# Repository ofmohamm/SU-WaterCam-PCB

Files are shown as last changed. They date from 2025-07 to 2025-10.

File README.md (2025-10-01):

# SU WaterCam PCB

This repository contains the KiCad design files for a custom PCB for **SU-WaterCam**, integrating the FLIR Lepton thermal camera, Bosch BNO055 IMU, Multitech mDot LoRa module, and Witty Pi 4 RTC board. 

---

## 🔧 Design Overview

- **Layers**: 2-layer PCB (F.Cu, B.Cu)
- **Components**:
  - FLIR Lepton thermal imaging module
  - Bosch BNO055 9-DOF absolute orientation sensor
  - Multitech mDot LoRa module
  - Witty Pi 4 RTC and power manager
- **Power Domains**:
  - 3.3V and 5V rails with copper fill zones
  - Mounting via Witty Pi 4-compatible headers
- **Interfaces**:
  - FFC cutout for FLIR Lepton
  - I²C / UART routing for sensors
  - LoRa antenna trace or u.FL footprint

---

## Electrical & Layout Highlights

- **Trace widths**:
  - Signal: 0.25 mm
  - Power: 0.5 mm (5V rail)
- **Clearance**: 0.20 mm (net class default)
- **Mechanical**:
  - Slot for ribbon cable (Edge.Cuts layer)
  - Mounting holes aligned for case/enclosure compatibility

---

## Custom Libraries

The project uses custom symbols and footprints located in:

- `symbols/mDOT.kicad_sym`
- `footprints/FLIR Lepton.pretty`
- `footprints/MDOT.pretty`
- `footprints/Witty Pi 4.pretty`

Library tables (`fp-lib-table` and `sym-lib-table`) are included and use relative paths for portability.

---

## 📷 PCB Images  

- **Wiring/Layout Diagram**  
  Wiring/Layout Diagram of SU-WaterCam PCB  

- **PCB Render**  
  3D Render of SU-WaterCam PCB

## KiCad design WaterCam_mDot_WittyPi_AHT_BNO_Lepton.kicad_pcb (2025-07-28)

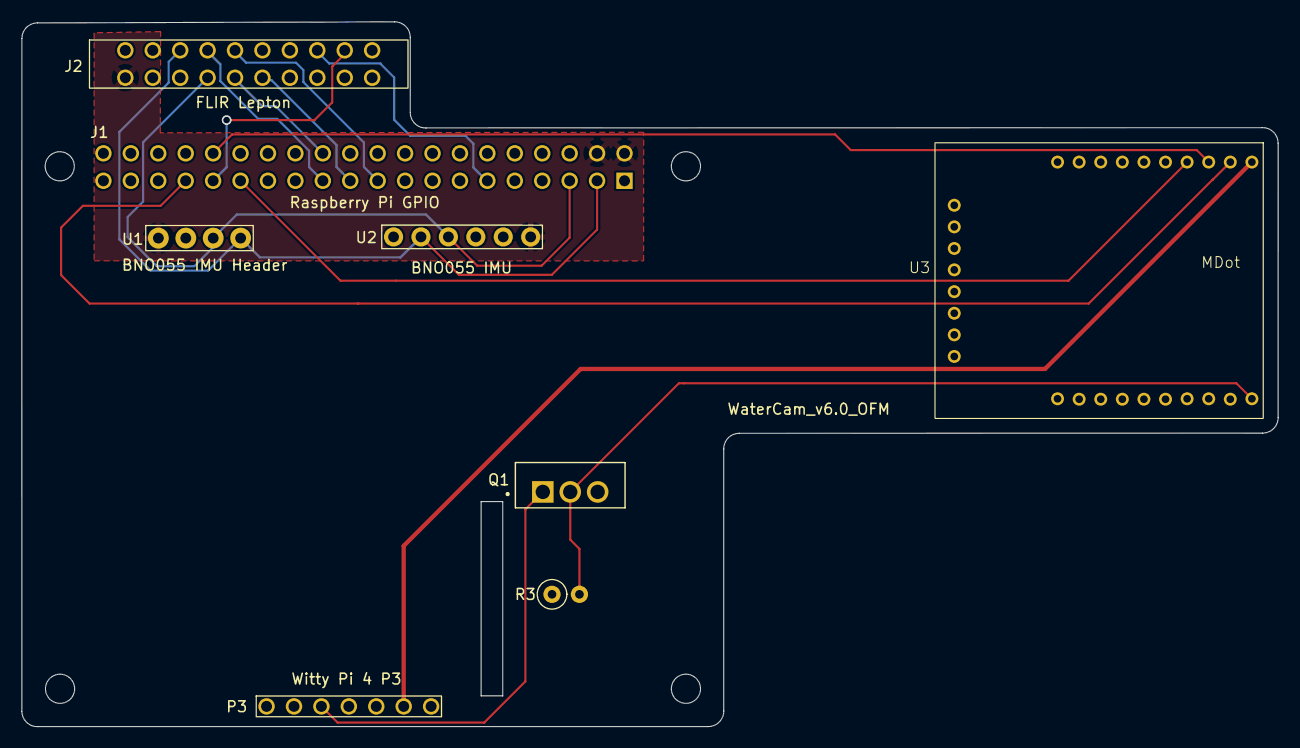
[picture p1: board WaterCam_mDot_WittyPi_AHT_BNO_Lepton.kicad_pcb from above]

Board: 2 copper layers, 116.3 x 65.3 mm, 8 parts (1 on the bottom side), 16 nets.

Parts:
J1: GPIO; MODULE_RASPBERRY_PI_4B_4GB
J2: FLIR Lepton; FLIR Lepton Breakout Board (Vertical)
P3: Witty Pi 4 P3; WittyPi4_Simple
Q1: NMOS; TO254P1067X483X2057-3
R3: 10kΩ Resistor; R_Axial_DIN0207_L6.3mm_D2.5mm_P2.54mm_Vertical
U1: ATH20; AHT20 Breakout Board
U2: BNO055 IMU; BNO-055 Breakout
U3: MDOT; MTDOT

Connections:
+5V: J1.2, J1.4, J2.2, U1.1 (VIN), U2.6 (VIN)
/GPIO2/SDA1: J1.3, J2.5, U1.4 (SDA), U2.2 (SDA)
/GPIO3/SCL1: J1.5, J2.8, U1.3 (SCL), U2.3 (SCL)
/GPIO5: J1.29, U3.4 (PA_6)
/GPIO6: J1.31, J2.17
/GPIO8/SPI0.CE0: J1.24, J2.10
/GPIO9/SPI0.MISO: J1.21, J2.12
/GPIO10/SPI0.MOSI: J1.19, J2.9
/GPIO11/SPI0.SCLK: J1.23, J2.7
/GPIO12/PWM0: J1.32, U3.3 (PA_3)
/GPIO13/PWM1: J1.33, U3.2 (PA_2)
/GPIO17: J1.11, J2.15
GND: J1.6, J1.9, J1.14, J1.20, J1.25, J1.30, J1.34, J1.39, J2.1, P3.7 (GND), Q1.3 (S), R3.1, U1.2 (GND), U2.4 (GND), U3.10 (GND)
unnamed: P3.2 (3V3), U3.1 (VDD)
unnamed: P3.5 (SW), Q1.1 (D)
unnamed: Q1.2 (G), R3.2, U3.19 (PB_1)

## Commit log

2025-03-12 work in progress schematic for Pi HAT connecting Lepton, mDot, BNO055, AHT20, and WittyPi
    [WaterCam_mDot_WittyPi_AHT_BNO_Lepton.kicad_sch]
2025-03-13 Replace power symbols with direct links to pins
    [WaterCam_mDot_WittyPi_AHT_BNO_Lepton.kicad_sch]
2025-03-14 add footprints for some elements
    [WaterCam_mDot_WittyPi_AHT_BNO_Lepton.kicad_sch]
2025-06-10 feat: complete PCB schematic
    Finalize placement and routing of components. Improve labeling for clarity.
    [WaterCam_mDot_WittyPi_AHT_BNO_Lepton.kicad_sch]
2025-07-21 Add initial WaterCam PCB design integrating FLIR Lepton, BNO055, mDot, and Witty Pi 4
    - Added schematic and PCB layout for 2-layer board in KiCad
    - Integrated custom symbols and footprints (FLIR Lepton, mDot, Witty Pi 4)
    - Included FFC slot for AWM 20624 15-pin ribbon cable
    - Routed 5V and GND copper fills with thermal reliefs
    - Verified design rule compliance (DRC clean)
    - Project includes local symbol and footprint tables for portability
    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
    [WaterCam_mDot_WittyPi_AHT_BNO_Lepton.kicad_pcb, WaterCam_mDot_WittyPi_AHT_BNO_Lepton.kicad_sch]
2025-07-23 Refine PCB power and ground layout for improved integrity and manufacturability
    - Localized 5V plane to FLIR and IMU region to reduce EMI and isolate power
    - Maintained full-board GND plane on bottom layer for low-impedance return paths
    - Verified through-hole pad connections to both copper layers
    - Removed unnecessary global power fills to prevent noise injection
    - Cleaned up trace routing and ensured adequate spacing from board edges
    [WaterCam_mDot_WittyPi_AHT_BNO_Lepton.kicad_pcb, WaterCam_mDot_WittyPi_AHT_BNO_Lepton.kicad_sch]
2025-07-28 Refactor silkscreen, component labels, and routing to align with Raspberry Pi and improve power integrity
    [WaterCam_mDot_WittyPi_AHT_BNO_Lepton-B_Cu.gbr, WaterCam_mDot_WittyPi_AHT_BNO_Lepton-B_Mask.gbr, WaterCam_mDot_WittyPi_AHT_BNO_Lepton-B_Paste.gbr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]
